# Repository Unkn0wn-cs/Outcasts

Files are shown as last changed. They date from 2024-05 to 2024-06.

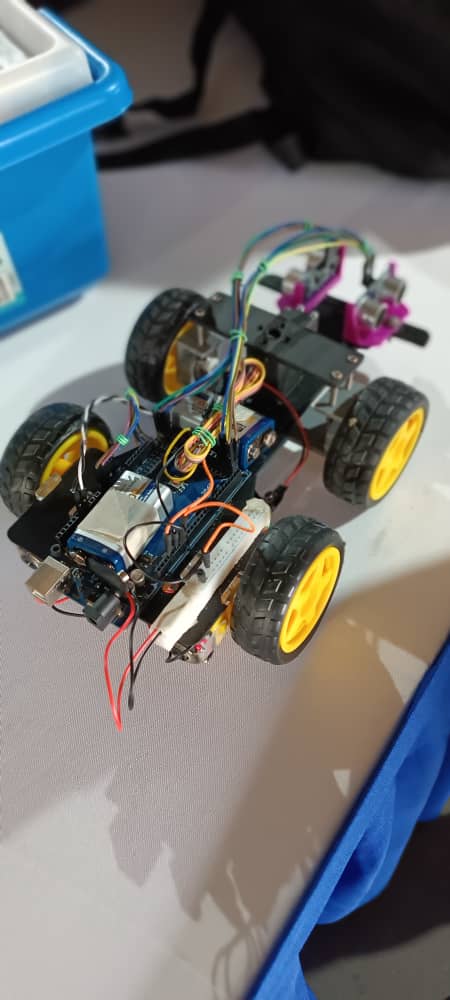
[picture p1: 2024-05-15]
v-photos/v0.31.jpg

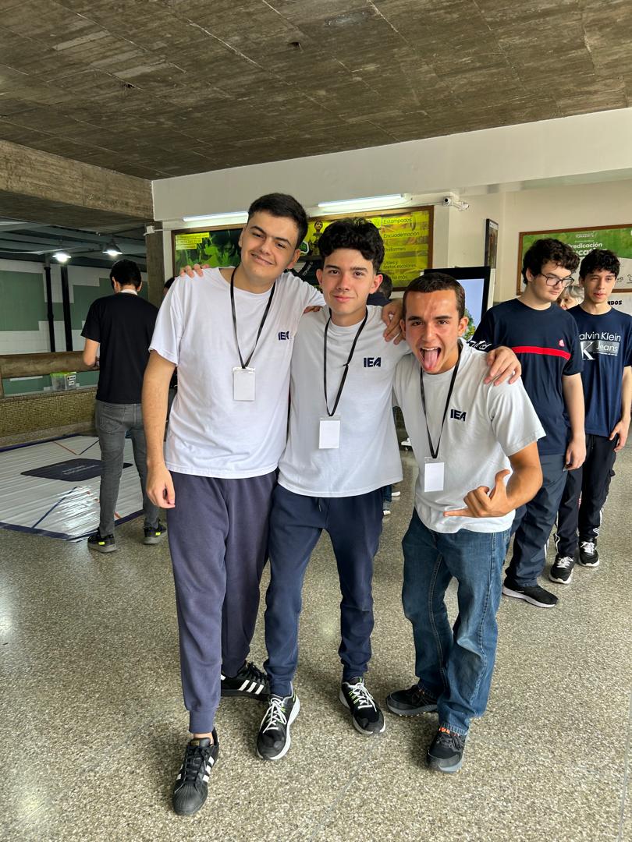
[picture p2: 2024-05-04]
t-photos/Chill .jpg

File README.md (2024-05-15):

Engineering materials
====
- 3d printed chasis (C:\Users\samue\OneDrive\Documents\Outcasts\models\Models\Placa Base Robot V4.stl)
- Arduino Mega 2560 
- 2 protoboards 
- Motor driver L298N
- 2 9v battery 
- 2 Ultrasonic sensors 
- 2 dc motors with gears 
- lots of cables and duck tape ;)

the world is our canvas. The future is ours.

## Project

We will explain briefly how we developed kratos and why we made the engineering desicions that lead to this prototype. This section will only cover the latest version of the robot.

- Mobility Management

We used 2 standard dc motors both managed by the L298n motor driver. this driver is conected to the Arduino mega digital ports and to an external standard 9v battery. The driver allows us to chose the speed and orientation of the dc motors, these may move foward or in opposite directions when the car is turning. these are attached to the back of the chassis and under the main piece. 

For steering we used a standard size servo mg996r located at the front of the chasis connected to the 3d printed steering structure (C:\Users\samue\OneDrive\Documents\Outcasts\models\Models\Acople para rueda y rodamiento.STL) the servo's signal cable is connected to the 40th pin of the board and moves from 60 degrees all the way up to 120 degrees.

The chassis is composed of 3 pieces: the base (C:\Users\samue\OneDrive\Documents\Outcasts\models\Models\Placa Base Robot V4.stl) and the steering mechanism (C:\Users\samue\OneDrive\Documents\Outcasts\models\Models\Acople para rueda y rodamiento.STL).

- Power and Sense Management

To power Kratos we are using 2 9v batteries, one is connected directly to the motor drive and the other is connected to the mega at it's vin and GND ports. These are rechargable and can store up to 600 mAh. To sense it's eviroment we included 2 ulstrasonic sensors one at each side, these are connected to the 53, 51, 24, 22 pins of the mega and detect whether or not there's a wall to it's side, if the aswer is negative it'll turn making sure it's always on the right path. 

Full length programs are stored here (C:\Users\samue\OneDrive\Documents\Outcasts\src\Full) other programs or testing code is stored here (C:\Users\samue\OneDrive\Documents\Outcasts\src).

- Obstacle Management

For v0.3 we used 2 ulstrasonic sensors to ensure it would follow the path of the track and avoid the walls. we will not have full obstacle evasion until the camera is installed which we plan to do before v0.4, we will implement the pixy 2.1 and have it analize the blocks in front of it to avoid them acordingly (this is not finished as of 5/14/24).

## Logs

v0.1: For this first prototype we designed a simple robot that simply circles the track in patter like way for 3 loops. We did not implement any sensors on the first version due to the instability that these had prior to the first competition. We used a motor drive to move the car forth, this motor is located under the chasis. We used a standard servo to steer the car with a 3d printed steering structure.

v0.2: This time arround we implemented ultrasonic sensors to ensure the robot turns the edges correctly, we used a simple condition that checks wether or not there's a wall to the side of the sensor, if the output is negative the robot will turn. The robot is too fast and the sensors have trouble recongnizing walls. 

v0.3: We polished the sensors and installed a new support for them. we also used the ENA & ENB ports of the motor driver to contro the speed and increase the sensors precision.

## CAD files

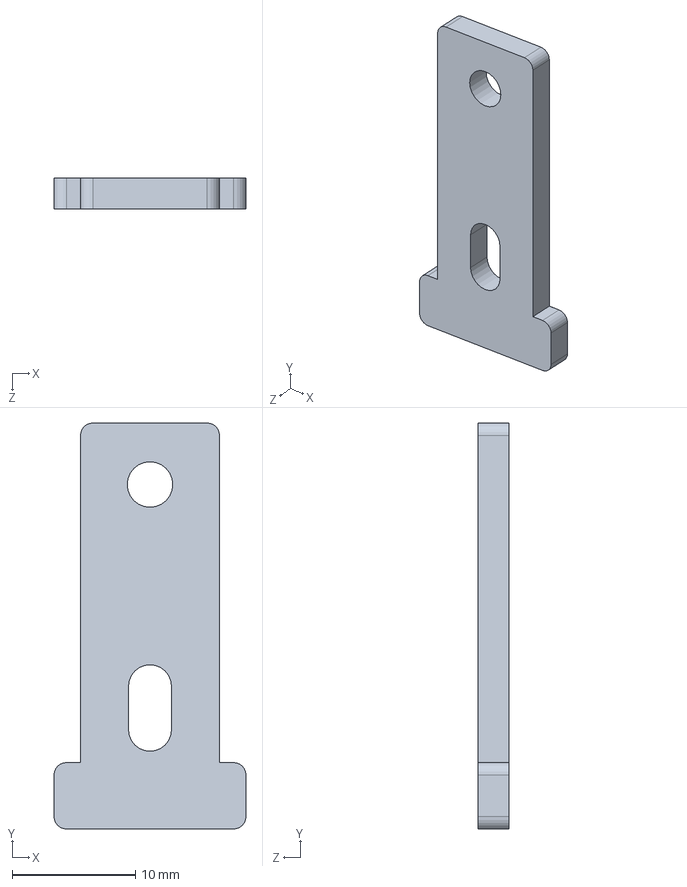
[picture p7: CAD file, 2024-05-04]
models/Models/Pieza para motor placa.SLDPRT
15.6 x 33.0 x 2.50 mm

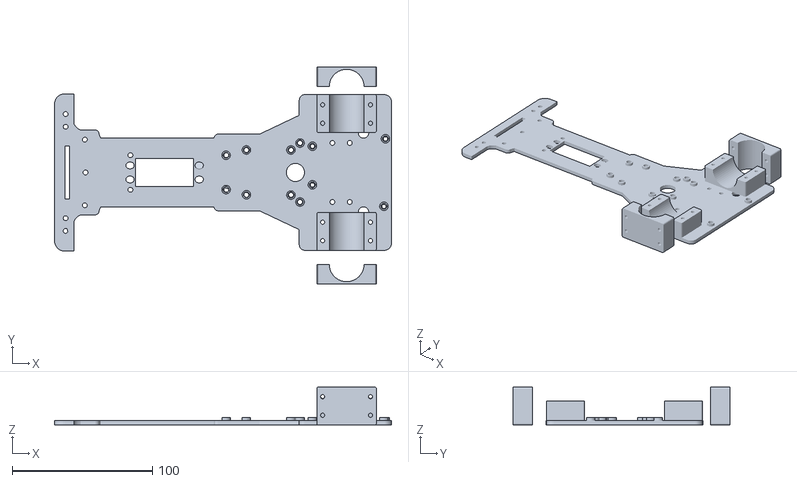
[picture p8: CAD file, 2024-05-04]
models/Models/Placa Base Robot V4.stl
240.4 x 154.9 x 27.0

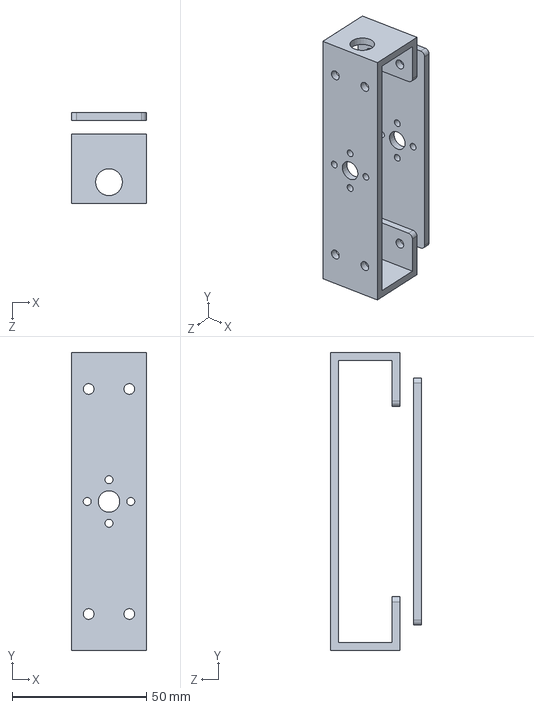
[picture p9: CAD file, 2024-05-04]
models/Models/Placa Base Robot.SLDPRT
28.0 x 110.8 x 34.0 mm

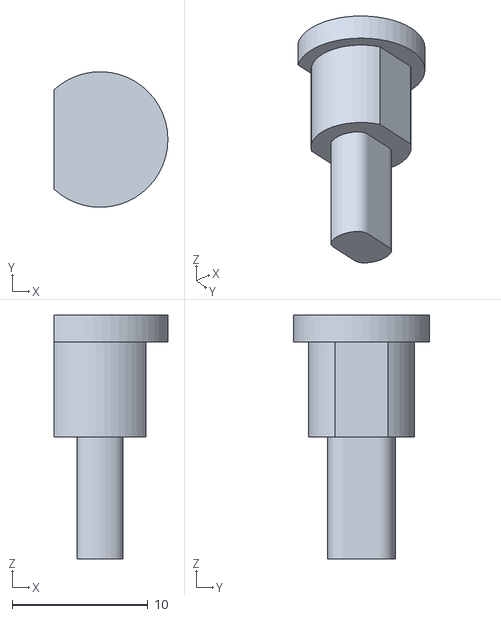
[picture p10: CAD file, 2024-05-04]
models/Models/Acople para rueda y rodamiento.STL
8.40 x 10.00 x 18.0

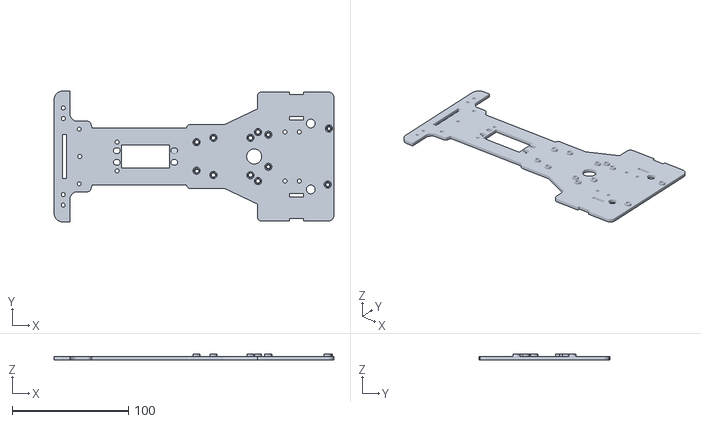
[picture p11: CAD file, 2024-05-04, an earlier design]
models/Models/Placa Base Robot V3.stl
240.4 x 112.3 x 5.03

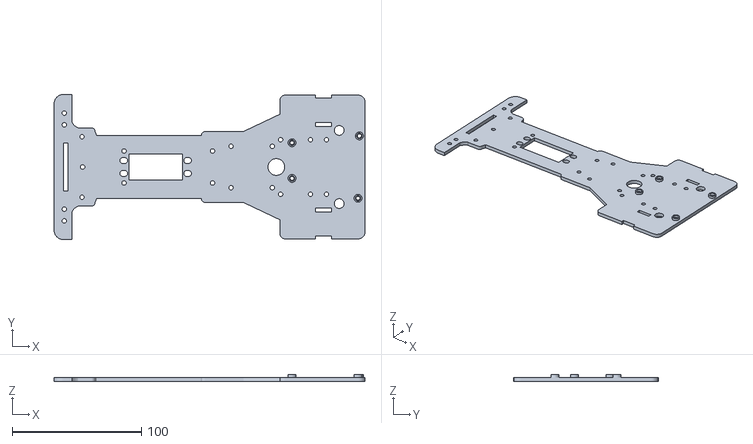
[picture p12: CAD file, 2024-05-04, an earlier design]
models/Models/Placa Base Robot V2.stl
240.4 x 112.3 x 5.03

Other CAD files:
models/Models/Placa Base Robot.STL

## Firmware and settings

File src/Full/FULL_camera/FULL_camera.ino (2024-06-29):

//6/26/24
//Arround the 
#include <Servo.h>
#include <Pixy2.h>

// This is the main Pixy object 
Pixy2 pixy;
Servo myservo;

// Ultrasomnic Trigonometry
const int trigPin1 = 10;
const int echoPin1 = 9;
const int trigPin2 = 13;
const int echoPin2 = 12;

//Funtions ------------------------------------------------------------------
  void fw();
  void rr();
  void rl();
  //void highen();

void setup() {
  // Pins, Ultrasonic sensors, servos
  //Ultrasonic ----------------------------------------------------------------
    Serial.begin(9600);
    pinMode(trigPin1,OUTPUT);
    pinMode(echoPin1,INPUT);
    pinMode(trigPin2,OUTPUT);
    pinMode(echoPin2,INPUT);

  //Servos -------------------------------------------------------------------
    myservo.attach(7);  // attaches the servo on pin 7 to the servo object

  //PIXY
   Serial.begin(9600);
  Serial.print("Starting...\n");
  
  pixy.init();

  //Pins -----------------------------------------------------------------------
  pinMode(4, OUTPUT);
  pinMode(3, OUTPUT);
  //
  pinMode(2, OUTPUT);
}

void loop() {
//Fw-----------------
  fw();
//Ultrasonic detection -----------------------------------------------------
    long dleft, dright, left, right;

  digitalWrite(trigPin1, LOW);
  delayMicroseconds(2);
  digitalWrite(trigPin1, HIGH);
  delayMicroseconds(10);
  digitalWrite(trigPin1, LOW);
  
  dleft = pulseIn(echoPin1, HIGH);
  left = microsecondsToCentimeters(dleft);
  Serial.print(left);
  Serial.println(", ");

  //delay(100);

  digitalWrite(trigPin2, LOW);
  delayMicroseconds(2);
  digitalWrite(trigPin2, HIGH);
  delayMicroseconds(10);
  digitalWrite(trigPin2, LOW);
  
  dright = pulseIn(echoPin2, HIGH);
  right = microsecondsToCentimeters(dright);
  Serial.print(right);
  Serial.println();

  delay(100);

//Conditionals --------------------------------------------------------------------------------------------------------------------------------------
  if  (left > 149 && left < 400){
    while (left > 149 && left < 400){
    rr(2500, 120);}
  } else if (right > 149 && right < 400){
    while (right > 149 && right < 400){
    rl(2500, 60);}
  } else   if (left > 149 && left < 400){
    while (left > 149 && left < 400){
    rr(2500, 120);}
  } else if (right > 149 && right < 400){
    while (right > 149 && right < 400){
    rl(2500, 60);}
  }else {
        
  //Camara ------------------------------------------------------------------------------------------------------------------------------------------
        int i; 
  // grab blocks!
  pixy.ccc.getBlocks();
  
  // If there are detect blocks, print them!
  if (pixy.ccc.numBlocks){
      if (pixy.ccc.blocks[i].m_signature == 1)
  {
    Serial.print("Block 1\n");
    myservo.write(45);
    delay (1000);
    myservo.write(135);
    delay (700);
    myservo.write(90);
    

  } else if (pixy.ccc.blocks[i].m_signature == 2){
    Serial.print("Block 2\n");
    myservo.write(135);
    delay (1000);
    myservo.write(45);
    delay (700);
    myservo.write(90);
  }
  }
  }

}



void rr(int t, int d){
  myservo.write(145);              
}

void rl(int t, int d){
  myservo.write(35);              
}

void fw(){
  analogWrite(2, 255);
  
  myservo.write(90); 

  digitalWrite(4, HIGH);
  digitalWrite(3, LOW);


}

void highen (){
  int i = 250;
  analogWrite(10, 255);
  analogWrite(11, 90);
}

long microsecondsToCentimeters(long microseconds) {
  // The speed of sound is 340 m/s or 29 microseconds per centimeter.
  // The ping travels out and back, so to find the distance of the object we
  // take half of the distance travelled.
  return microseconds / 29 / 2;
}

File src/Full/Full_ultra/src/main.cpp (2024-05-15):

#include <Arduino.h>
#include <Servo.h>

Servo myservo;
// Ultrasomnic Trigonometry
const int trigPin1 = 53;
const int echoPin1 = 51;
const int trigPin2 = 22;
const int echoPin2 = 24;

//Funtions ------------------------------------------------------------------

void highen (){
    analogWrite(9, 175);
    analogWrite(8, 175);
  }

void rr(int i, int d){
    highen();

    myservo.write(120);              


    digitalWrite(2, HIGH);
    digitalWrite(3, LOW);
    digitalWrite(4, LOW);
    digitalWrite(5, HIGH);

    delay (i);
  }

void rl(int i, int d){
    highen();

    myservo.write(60);              

    digitalWrite(2, LOW);
    digitalWrite(3, HIGH);
    digitalWrite(4, HIGH);
    digitalWrite(5, LOW);

    delay (i);
  }

void fw(){
    analogWrite(9, 165);
    analogWrite(8, 165);  
    
    myservo.write(93); 

    digitalWrite(2, HIGH);
    digitalWrite(3, LOW);
    digitalWrite(4, HIGH);
    digitalWrite(5, LOW);

  }

long microsecondsToCentimeters(long microseconds) {
    // The speed of sound is 340 m/s or 29 microseconds per centimeter.
    // The ping travels out and back, so to find the distance of the object we
    // take half of the distance travelled.
    return microseconds / 29 / 2;
  }


void setup() {
  // Pins, Ultrasonic sensors, servos
  //Ultrasonic ----------------------------------------------------------------
    Serial.begin(9600);
    pinMode(trigPin1,OUTPUT);
    pinMode(echoPin1,INPUT);
    pinMode(trigPin2,OUTPUT); 
    pinMode(echoPin2,INPUT);

  //Servos -------------------------------------------------------------------
    myservo.attach(40);  // attaches the servo on pin 9 to the servo object


  //Pins -----------------------------------------------------------------------
  pinMode(2, OUTPUT);
  pinMode(3, OUTPUT);
  pinMode(4, OUTPUT);
  pinMode(5, OUTPUT);
  //
  pinMode(8, OUTPUT);
  pinMode(9, OUTPUT);

  analogWrite(9, 100);
  analogWrite(8, 100);

}

void loop() {
//Fw-----------------
  fw();

  delay(1000);
  
//Ultrasonic detection -----------------------------------------------------
    long dleft, dright, left, right;

  digitalWrite(trigPin1, LOW);
  delayMicroseconds(2);
  digitalWrite(trigPin1, HIGH);
  delayMicroseconds(10);
  digitalWrite(trigPin1, LOW);
  
  dleft = pulseIn(echoPin1, HIGH);
  left = microsecondsToCentimeters(dleft);
  Serial.print(left);
  Serial.println(", ");

  delay(100);

  digitalWrite(trigPin2, LOW);
  delayMicroseconds(2);
  digitalWrite(trigPin2, HIGH);
  delayMicroseconds(10);
  digitalWrite(trigPin2, LOW);
  
  dright = pulseIn(echoPin2, HIGH);
  right = microsecondsToCentimeters(dright);
  Serial.print(right);
  Serial.println();

  delay(100);

//Conditionals 
  if (left > 80 && left < 150 ){
    rr(500, 105);
  } else if (right > 80 && right < 150){
    rl(500, 75);
  } else if (left > 149 && left < 400){
    rr(750, 120);
  } else if (right > 149 && right < 400){
    rl(750, 60);
  } else   if (left > 80 && left < 150 ){
    rr(500, 105);
  } else if (right > 80 && right < 150){
    rl(500, 75);
  } else if (left > 149 && left < 400){
    rr(750, 120);
  } else if (right > 149 && right < 400){
    rl(750, 60);
  } 

}

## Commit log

2024-05-04 Main models used in our build
    [Acople para rueda y rodamiento.STL, Pieza para motor placa.SLDPRT, Placa Base Robot V2.stl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]
2024-05-04 mighty Kratos
    all the photos of the first prototype of our robot
2024-05-11 Ultrasonic sensors
    We implemented ultrasonic sensors to detect corners and where it is that the robot should turn.
2024-05-15 v0.3
    Documented the first autonomous prototype
2024-06-29 v0.5
    UCAB
    -added scheme
    -Added models and parts
    -added camera
